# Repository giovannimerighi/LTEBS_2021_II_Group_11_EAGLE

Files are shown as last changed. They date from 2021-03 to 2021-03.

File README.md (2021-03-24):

# LTEBS_2021_II_Group_11_EAGLE

**Final Version**

The purpose of this project consists in designing a PCB embedding the PSoC 5LP micro-controller in order to evaluate the performance of the micro-controller itself 
to assess if such uC is suitable for the project requested by the customer.
The deisgned PCB embeds the CY8CKIT-059, namely the development kit for the PSoC 5LP, and additional components required to perform the testing.

The project involves, in addition to the schematic and the board desing, a library containing custom components and Design Rules implemented according to the technical 
specifications reported in the website of the manufacturer, namely the MDSrl.

---

## Contributors
* Alessia Pesenti
* Elena Stocco
* Giovanni Merighi

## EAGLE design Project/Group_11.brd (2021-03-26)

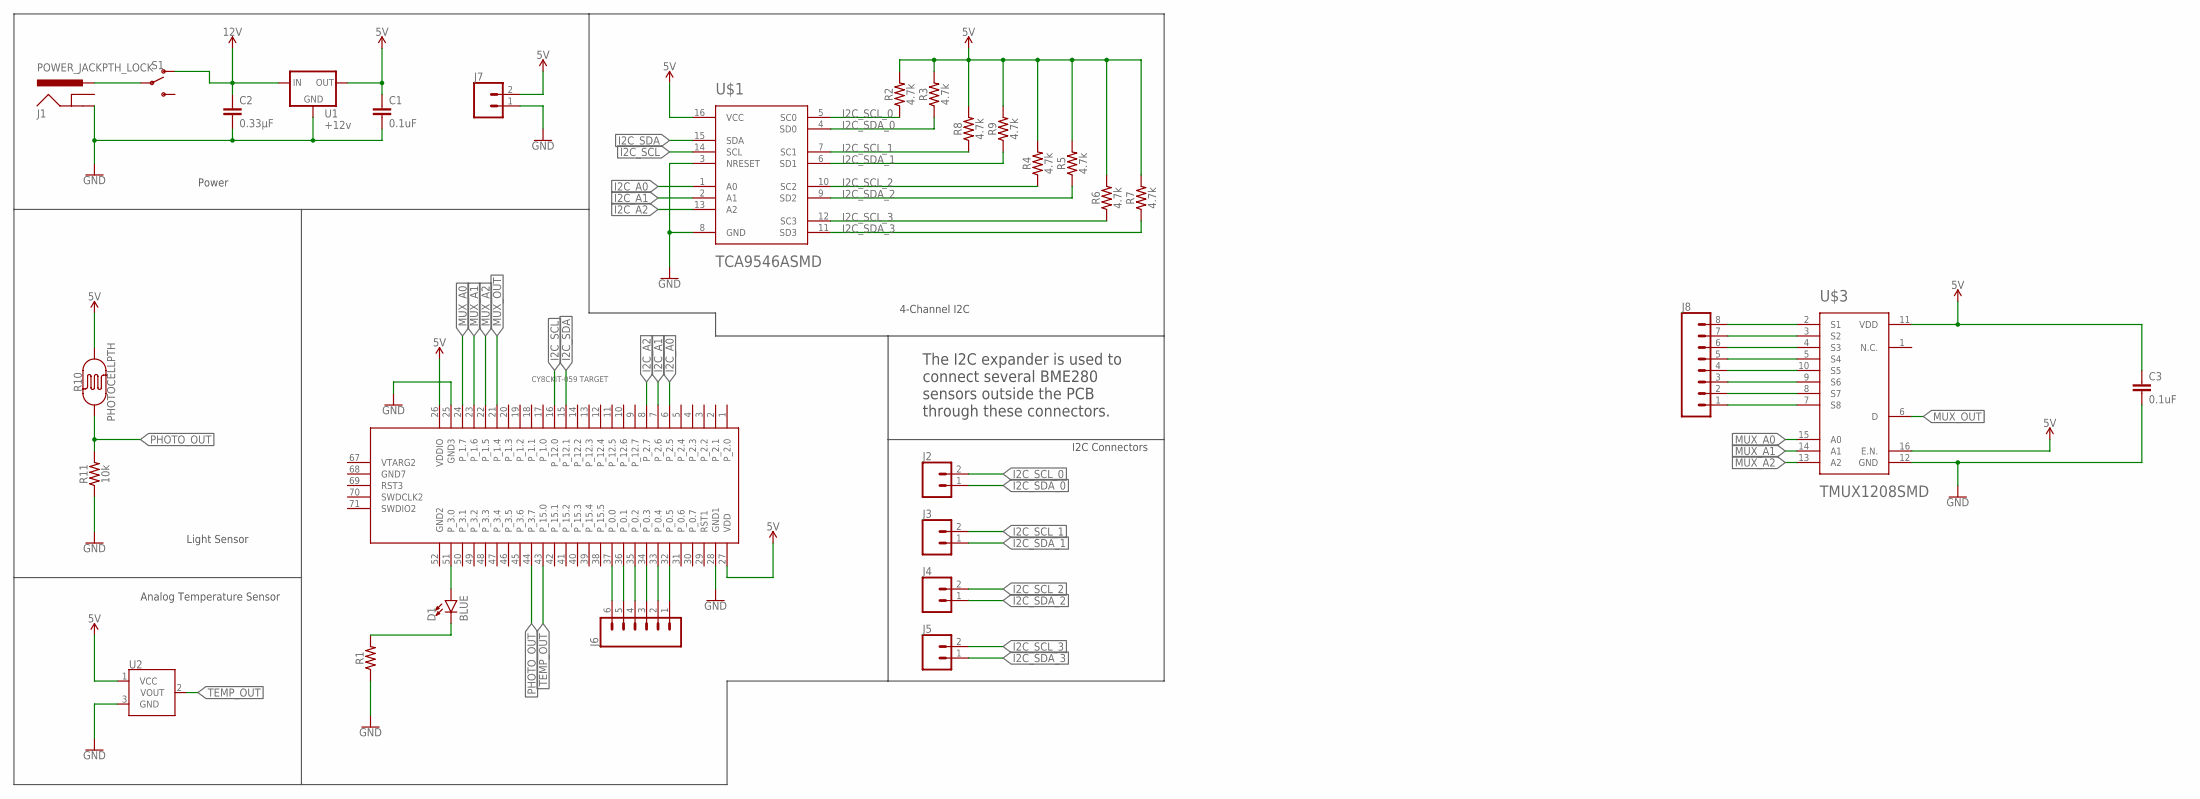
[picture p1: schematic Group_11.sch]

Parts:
C1, C3: 0.1uF; CAP-PTH-SMALL-KIT
C2: 0.33µF; 0805
D1: BLUE; LED-1206
J1: POWER_JACKPTH_LOCK; POWER_JACK_PTH_LOCK
J2, J3, J4, J5, J7: CONN_02; 1X02
J6: CONN_06LOCK; 1X06_LOCK
J8: CONN_08LOCK; 1X08_LOCK
R1: AXIAL-0.3
R2, R3, R4, R5, R6, R7, R8, R9: 4.7k; 0603
R10: PHOTOCELLPTH; PHOTOCELL
R11: 10k; 0603
S1: SWITCH-SPDT-PTH-11.6X4.0MM; SWITCH_SPDT_PTH_11.6X4.0MM
U1: +12v; TO-252
U2: TMP36GT9; TO-92
U$1: TCA9546ASMD; TSSOP-16
U$2: CY8CKIT-059_TARGET
U$3: TMUX1208SMD; QFN16

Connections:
5V: C1.1, C3.1, J7.2, R2.2, R3.2, R4.2, R5.2, R6.2, R7.2, R8.2, R9.2, R10.2, U1.2 (OUT), U2.1 (VCC), U$1.16 (VCC), U$2.26 (VDDIO), U$2.27 (VDD), U$3.11 (VDD), U$3.16 (E.N.)
12V: C2.1, S1.1 (O), U1.1 (IN)
GND: C1.2, C2.2, C3.2, J1.GND, J7.1, R1.P$1 (1), R11.1, U1.3 (GND), U2.3 (GND), U$1.3 (NRESET), U$1.8 (GND), U$2.25 (GND3), U$2.28 (GND1), U$3.12 (GND)
I2C_A0: U$1.1 (A0), U$2.6 (P_2.5)
I2C_A1: U$1.2 (A1), U$2.7 (P_2.6)
I2C_A2: U$1.13 (A2), U$2.8 (P_2.7)
I2C_SCL: U$1.14 (SCL), U$2.16 (P_12.0)
I2C_SCL_0: J2.2, R2.1, U$1.5 (SC0)
I2C_SCL_1: J3.2, R8.1, U$1.7 (SC1)
I2C_SCL_2: J4.2, R4.1, U$1.10 (SC2)
I2C_SCL_3: J5.2, R6.1, U$1.12 (SC3)
I2C_SDA: U$1.15 (SDA), U$2.15 (P_12.1)
I2C_SDA_0: J2.1, R3.1, U$1.4 (SD0)
I2C_SDA_1: J3.1, R9.1, U$1.6 (SD1)
I2C_SDA_2: J4.1, R5.1, U$1.9 (SD2)
I2C_SDA_3: J5.1, R7.1, U$1.11 (SD3)
MUX_A0: U$2.24 (P_1.7), U$3.15 (A0)
MUX_A1: U$2.23 (P_1.6), U$3.14 (A1)
MUX_A2: U$2.22 (P_1.5), U$3.13 (A2)
MUX_OUT: U$2.21 (P_1.4), U$3.6 (D)
unnamed: J8.8, U$3.2 (S1)
unnamed: D1.C, R1.P$2 (2)
unnamed: D1.A, U$2.51 (P_3.0)
unnamed: J6.6, U$2.37 (P_0.0)
unnamed: J6.5, U$2.36 (P_0.1)
unnamed: J6.4, U$2.35 (P_0.2)
unnamed: J6.3, U$2.34 (P_0.3)
unnamed: J6.2, U$2.33 (P_0.4)
unnamed: J1.PWR, S1.2
unnamed: J8.7, U$3.3 (S2)
unnamed: J8.1, U$3.7 (S8)
unnamed: J8.2, U$3.8 (S7)
unnamed: J8.3, U$3.9 (S6)
unnamed: J8.4, U$3.10 (S5)
unnamed: J8.5, U$3.5 (S4)
unnamed: J8.6, U$3.4 (S3)
unnamed: J6.1, U$2.32 (P_0.5)
PHOTO_OUT: R10.1, R11.2, U$2.44 (P_3.7)
TEMP_OUT: U2.2 (VOUT), U$2.43 (P_15.0)

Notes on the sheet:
Light Sensor
Analog Temperature Sensor
Power
I2C Connectors
The I2C expander is used to connect several BME280 sensors outside the PCB through these connectors.
4-Channel I2C

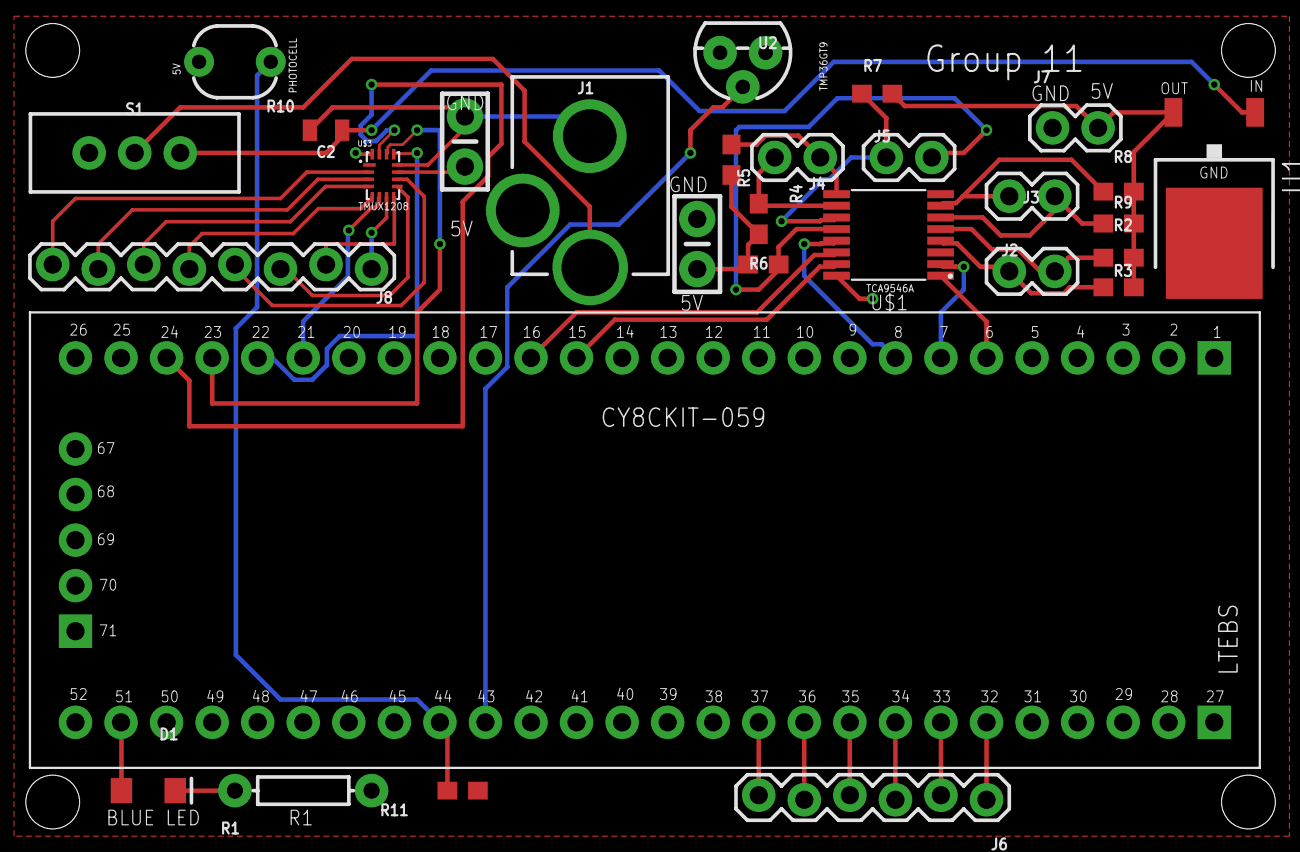
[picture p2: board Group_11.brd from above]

Board: 2 copper layers, 29 parts (0 on the bottom side), 39 nets.

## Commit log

2021-03-18 Prima Versione Schematico
    [Group_11.sch]
2021-03-19 Aggiunta dei Labels alla prima versione dello schematico
    [Group_11.sch]
2021-03-20 Organizzazione in cartelle
    [Group_11.sch]
2021-03-20 Modifica Labels I2C_SCL
    [Group_11.sch]
2021-03-20 Modifica di libreria e schematico su dev
    [Group_11.sch]
2021-03-20 Prima commit Board
    [Group_11.brd]
2021-03-20 Modifica symbols e schematico aggiornato
    [Group_11.brd, Group_11.sch]
2021-03-20 Aggiornamento board
    [Group_11.brd]
2021-03-21 Aggiunta GND
    [Group_11.sch]
2021-03-21 Aggiornamento parte inferiore
    [Group_11.brd]
2021-03-21 Board da verificare con Design Rules
    [Group_11.brd]
2021-03-21 Prova disposizione board
    [Group_11.brd]
2021-03-21 Aggiunta dei quattro fori alla board e riorganizzazione dei componenti
    [Group_11.brd]
2021-03-22 Versione corretta con path da 8 mil nel mux, holes da 3mm
    [Group_11.brd]
2021-03-22 Board senza errori
    [Group_11.brd]
2021-03-22 Correzione schematico collegamenti MUX
    [Group_11.brd, Group_11.sch]
2021-03-22 Aggiunta collegamenti board
    [Group_11.brd]
2021-03-22 Correzione clearance
    [Group_11.brd]
2021-03-23 Aggiunta silkscreen
    [Group_11.brd]
2021-03-24 Modifica isolate settings
    [Group_11.brd]
2021-03-25 Versione Revisionata
    [Group_11.brd]
2021-03-25 Dimensioni board
    [Group_11.brd]
2021-03-26 Modifica silkscreen
    [Group_11.brd]
2021-03-26 Aggiunta isolation
    [Group_11.brd]
2021-03-26 Final version
    [Group_11.brd]

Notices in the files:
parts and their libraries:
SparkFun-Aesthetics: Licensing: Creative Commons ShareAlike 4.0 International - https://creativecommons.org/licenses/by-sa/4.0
